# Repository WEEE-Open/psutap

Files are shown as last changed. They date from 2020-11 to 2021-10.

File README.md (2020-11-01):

# PSUtap
The PSUtap is a battery powered device designed to sit between the PSU (power supply unit) and the motherboard of a desktop computer.  
It's purpose is to constantly monitor the power lines (voltage and current) to detect power related issues: short circuits, open circuits, overloads, overvoltages, etc...   
It taps the lines from the main 24 pin ATX connector and the lines from another 4 pin connector to monitor:
* 12V1
* 12V2
* 5V
* 5VSB
* 3V3

## Structure of the device
The device is divided into three different boards, which are mounted on top of each other. From the bottom up, they are:
* the analog board
* the digital board
* the screen module  

The three are connected through male/female headers and communicate through an SPI interface.

## Analog board
This board gets its name from the fact that it has current sensing ICs, voltage sensing voltage dividers and an ADC to transmit the data to the digital board.  
For the current sensing, we've used some [LT6105](https://www.analog.com/media/en/technical-documentation/data-sheets/6105fa.pdf) ICs, which are essentially (differential) voltage controlled current sources. The configuration in our board is not much different than the typical application shown in the schematic.  
For the voltage sensing, we've used some regular voltage dividers, with a bit of margin so that we can also detect overvoltages.  
The ADC is an [AD7708](https://www.analog.com/media/en/technical-documentation/data-sheets/AD7708_7718.pdf), which is a delta-sigma, 16 bits, 10 channels ADC with integrated SPI interface, which is why we chose it, so that we could easily connect it to a uC without using too many wires.

## Digital Board
This board contains the uC, the brain of the entire device, a [CH340G](https://cdn.sparkfun.com/datasheets/Dev/Arduino/Other/CH340DS1.PDF) USB to serial converter,  the battery charging and protection circuit, a USB port and some buttons for the user input.  
The used uC is an [ATmega328P](https://ww1.microchip.com/downloads/en/DeviceDoc/Atmel-7810-Automotive-Microcontrollers-ATmega328P_Datasheet.pdf), which will be flashed with the Arduino bootloader so that it can be easily programmed through the Arduino IDE.  
Its main tasks are:
* reading the data coming from the ADC
* displaying on the screen
* handling user inputs
* interact with the computer through the USB port (data logging/remote control)

## Screen module
The screen module is a 240x320 2.8'' LCD, and the serial number is `tjctm24028-spi`.  
It's purpose is to show the user all the measured voltages and currents at once, so that a problem related with the power lines can be located very quickly, and also graph the voltages and currents wrt time.

## Current state
* The schematic for the analog and the digital board have been finished
* The PCB of the first board has to be redesigned completly
* The PCB of the second board has to be designed from scratch
* All the software for the microcontroller has to be written
* Testing (a lot of testing)

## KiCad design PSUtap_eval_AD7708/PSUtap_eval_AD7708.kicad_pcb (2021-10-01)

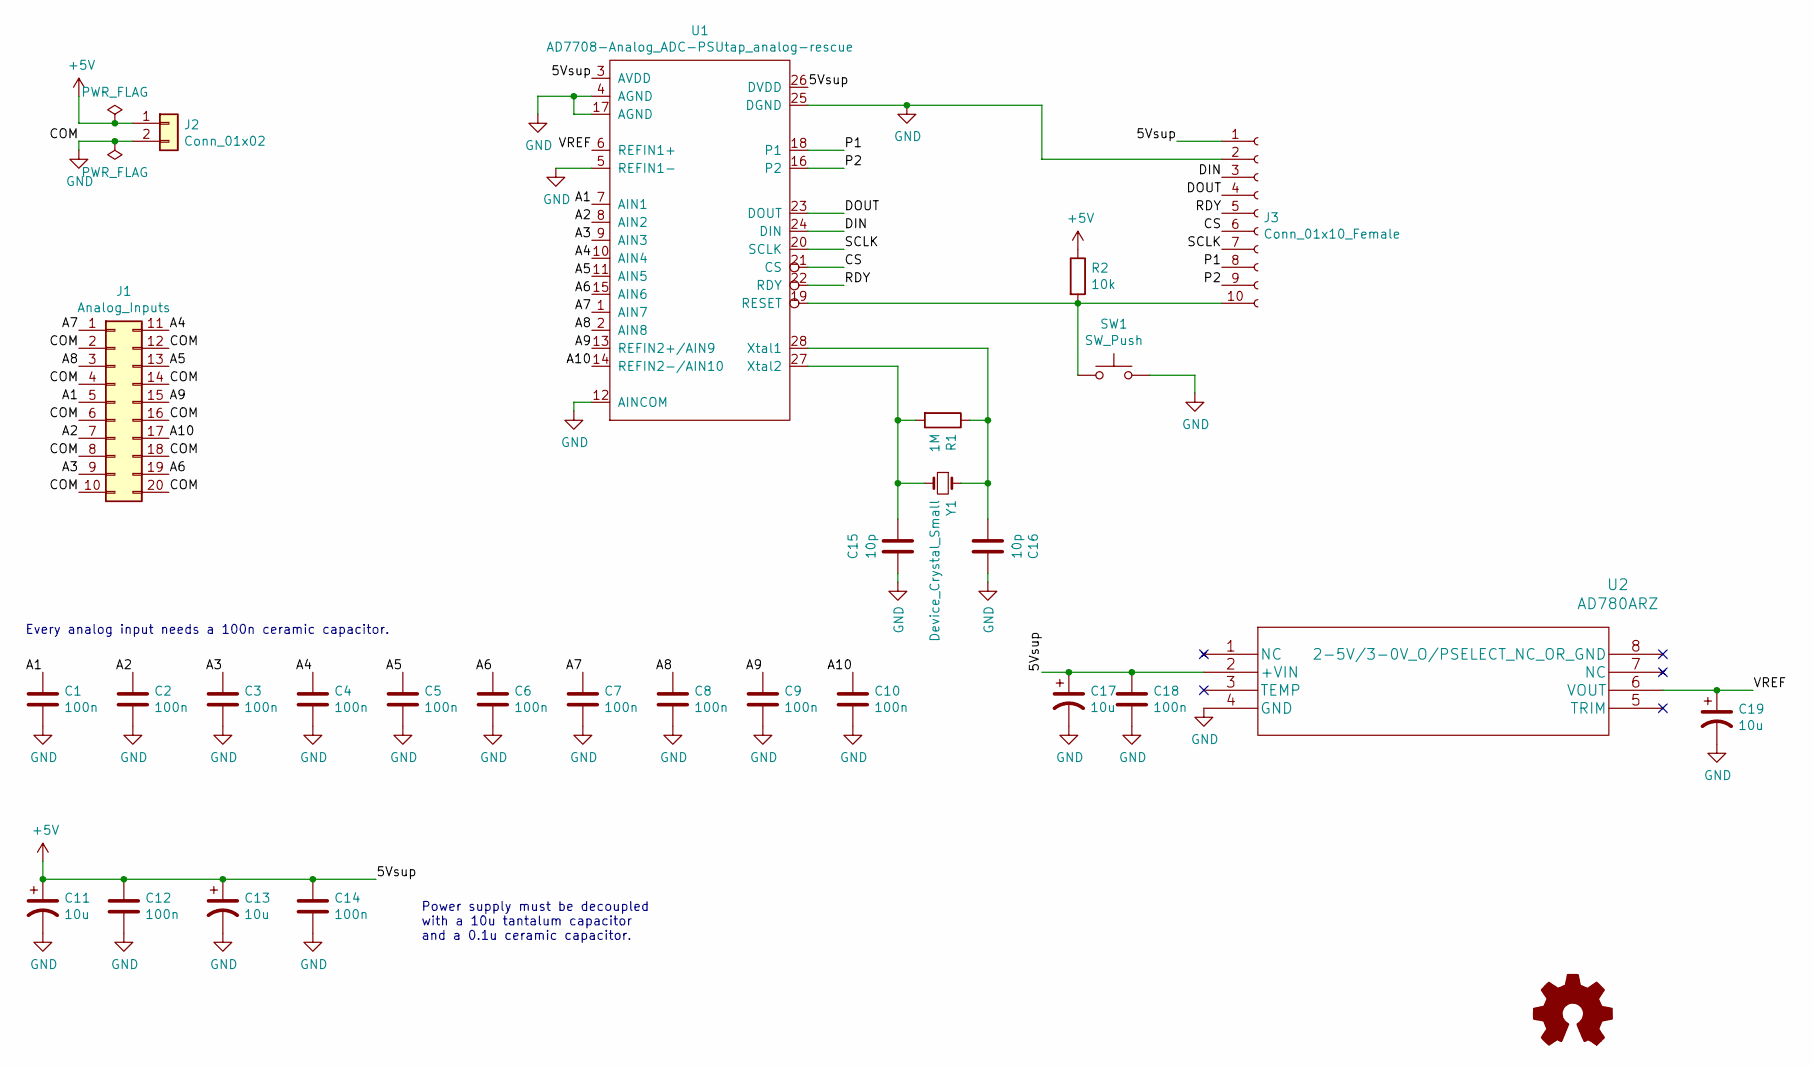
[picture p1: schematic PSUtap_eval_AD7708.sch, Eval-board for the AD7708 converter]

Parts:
C1, C2, C3, C4, C5, C6, C7, C8, C9, C10, C12, C14, C18: 100n; C_0603_1608Metric_Pad1.05x0.95mm_HandSolder
C11, C13, C17, C19: 10u; C_0805_2012Metric
C15, C16: 10p; C_0603_1608Metric_Pad1.05x0.95mm_HandSolder
J1: Analog_Inputs; PinSocket_2x10_P2.54mm_Vertical
J2: Conn_01x02; PinSocket_1x02_P2.54mm_Vertical
J3: Conn_01x10_Female; PinSocket_1x10_P2.54mm_Vertical
R1: 1M; R_0603_1608Metric_Pad1.05x0.95mm_HandSolder
R2: 10k; R_0603_1608Metric_Pad1.05x0.95mm_HandSolder
SW1: SW_Push; SW_SPST_B3U-1000P
U1: AD7708-Analog_ADC-PSUtap_analog-rescue; SOIC-28W_7.5x18.7mm_P1.27mm
U2: AD780ARZ; SSOP-8_3.9x5.05mm_P1.27mm
Y1: Device_Crystal_Small; Crystal_SMD_EuroQuartz_EQ161-2Pin_3.2x1.5mm_HandSoldering

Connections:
+5V: C11.1, C12.1, C13.1, C14.1, C17.1, C18.1, J2.1, J3.1, R2.1, U1.3 (AVDD), U1.26 (DVDD), U2.2 (+VIN)
/A1: C1.1, J1.5, U1.7 (AIN1)
/A2: C2.1, J1.7, U1.8 (AIN2)
/A3: C3.1, J1.9, U1.9 (AIN3)
/A4: C4.1, J1.11, U1.10 (AIN4)
/A5: C5.1, J1.13, U1.11 (AIN5)
/A6: C6.1, J1.19, U1.15 (AIN6)
/A7: C7.1, J1.1, U1.1 (AIN7)
/A8: C8.1, J1.3, U1.2 (AIN8)
/A9: C9.1, J1.15, U1.13 (REFIN2+/AIN9)
/A10: C10.1, J1.17, U1.14 (REFIN2-/AIN10)
/CS: J3.6, U1.21 (CS)
/DIN: J3.3, U1.24 (DIN)
/DOUT: J3.4, U1.23 (DOUT)
/P1: J3.8, U1.18 (P1)
/P2: J3.9, U1.16 (P2)
/RDY: J3.5, U1.22 (RDY)
/SCLK: J3.7, U1.20 (SCLK)
/VREF: C19.1, U1.6 (REFIN1+), U2.6 (VOUT); also elsewhere on the board
GND: C1.2, C2.2, C3.2, C4.2, C5.2, C6.2, C7.2, C8.2, C9.2, C10.2, C11.2, C12.2, C13.2, C14.2, C15.1, C16.1, C17.2, C18.2, C19.2, J1.2, J1.4, J1.6, J1.8, J1.10, J1.12, J1.14, J1.16, J1.18, J1.20, J2.2, J3.2, SW1.2, U1.4 (AGND), U1.5 (REFIN1-), U1.12 (AINCOM), U1.17 (AGND), U1.25 (DGND), U2.4 (GND)
unnamed: C15.2, R1.2, U1.27 (Xtal2), Y1.2
unnamed: C16.2, R1.1, U1.28 (Xtal1), Y1.1
unnamed: J3.10, R2.2, SW1.1, U1.19 (RESET)

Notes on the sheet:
Power supply must be decoupled with a 10u tantalum capacitor and a 0.1u ceramic capacitor.
Every analog input needs a 100n ceramic capacitor.

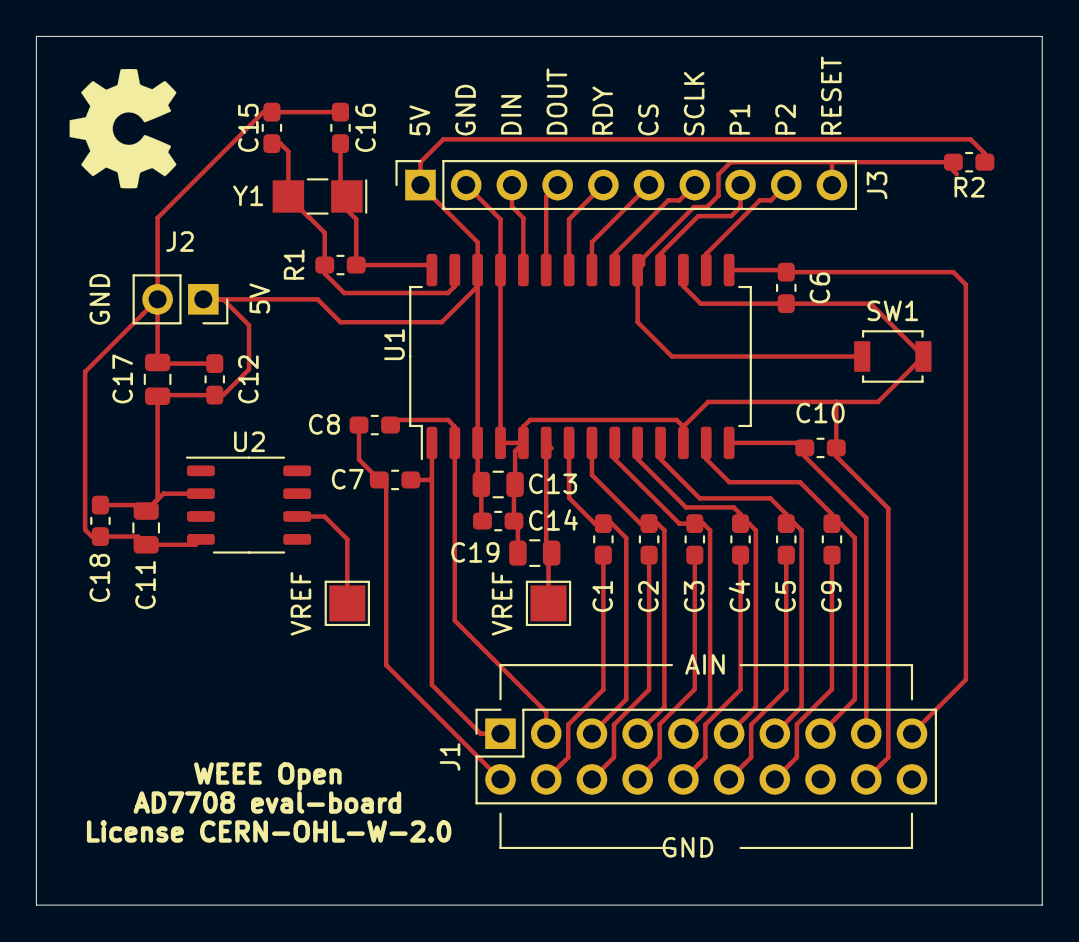
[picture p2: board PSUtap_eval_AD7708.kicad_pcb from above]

Board: 2 copper layers, 55.9 x 48.3 mm, 30 parts (0 on the bottom side), 23 nets.

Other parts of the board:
VREF: TestPoint_Pad_2.0x2.0mm
VREF#2: TestPoint_Pad_2.0x2.0mm

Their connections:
/VREF: VREF.1, VREF#2.1; also elsewhere on the board

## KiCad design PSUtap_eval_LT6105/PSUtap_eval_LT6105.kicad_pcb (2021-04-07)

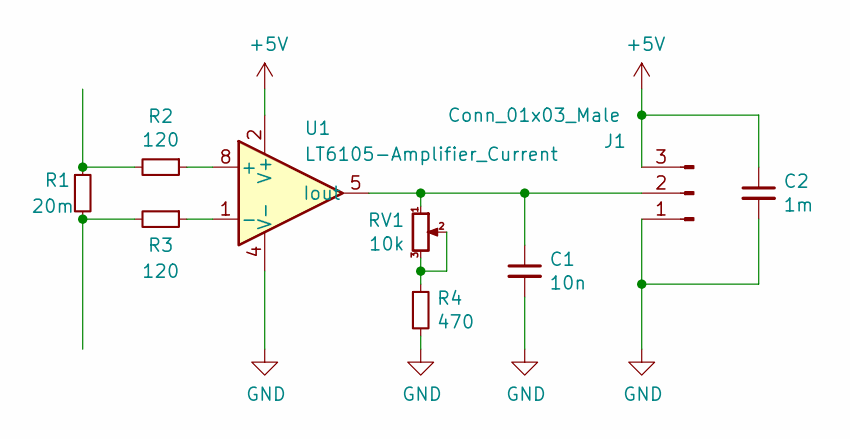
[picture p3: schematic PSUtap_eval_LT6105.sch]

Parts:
C1: 10n; C_0805_2012Metric_Pad1.18x1.45mm_HandSolder
C2: 1m; C_0805_2012Metric_Pad1.18x1.45mm_HandSolder
J1: Conn_01x03_Male; PinHeader_1x03_P2.54mm_Vertical
R1: 20m; R_2512_6332Metric_Pad1.40x3.35mm_HandSolder
R2, R3: 120; R_0805_2012Metric_Pad1.20x1.40mm_HandSolder
R4: 470; R_0805_2012Metric_Pad1.20x1.40mm_HandSolder
RV1: 10k; Potentiometer_Bourns_3296W_Vertical
U1: LT6105-Amplifier_Current; MSOP-8_3x3mm_P0.65mm

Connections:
+5V: C2.1, J1.3, U1.2 (V+)
GND: C1.2, C2.2, J1.1, R4.2, U1.4 (V-)
unnamed: C1.1, J1.2, RV1.1, U1.5 (Iout)
unnamed: R1.1, R2.2
unnamed: R1.2, R3.2
unnamed: R2.1, U1.8 (+)
unnamed: R3.1, U1.1 (-)
unnamed: R4.1, RV1.2, RV1.3

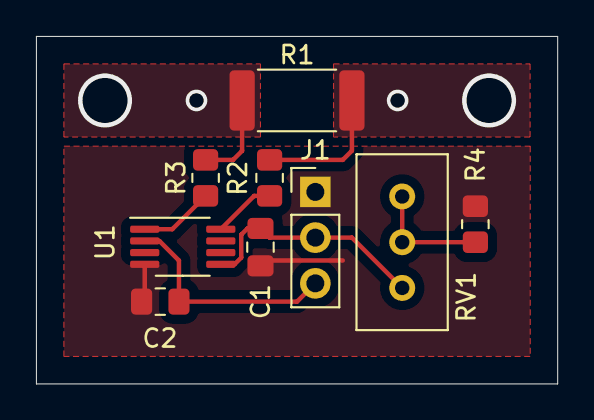
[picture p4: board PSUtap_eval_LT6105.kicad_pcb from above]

Board: 2 copper layers, 29.0 x 19.3 mm, 9 parts (0 on the bottom side), 8 nets.

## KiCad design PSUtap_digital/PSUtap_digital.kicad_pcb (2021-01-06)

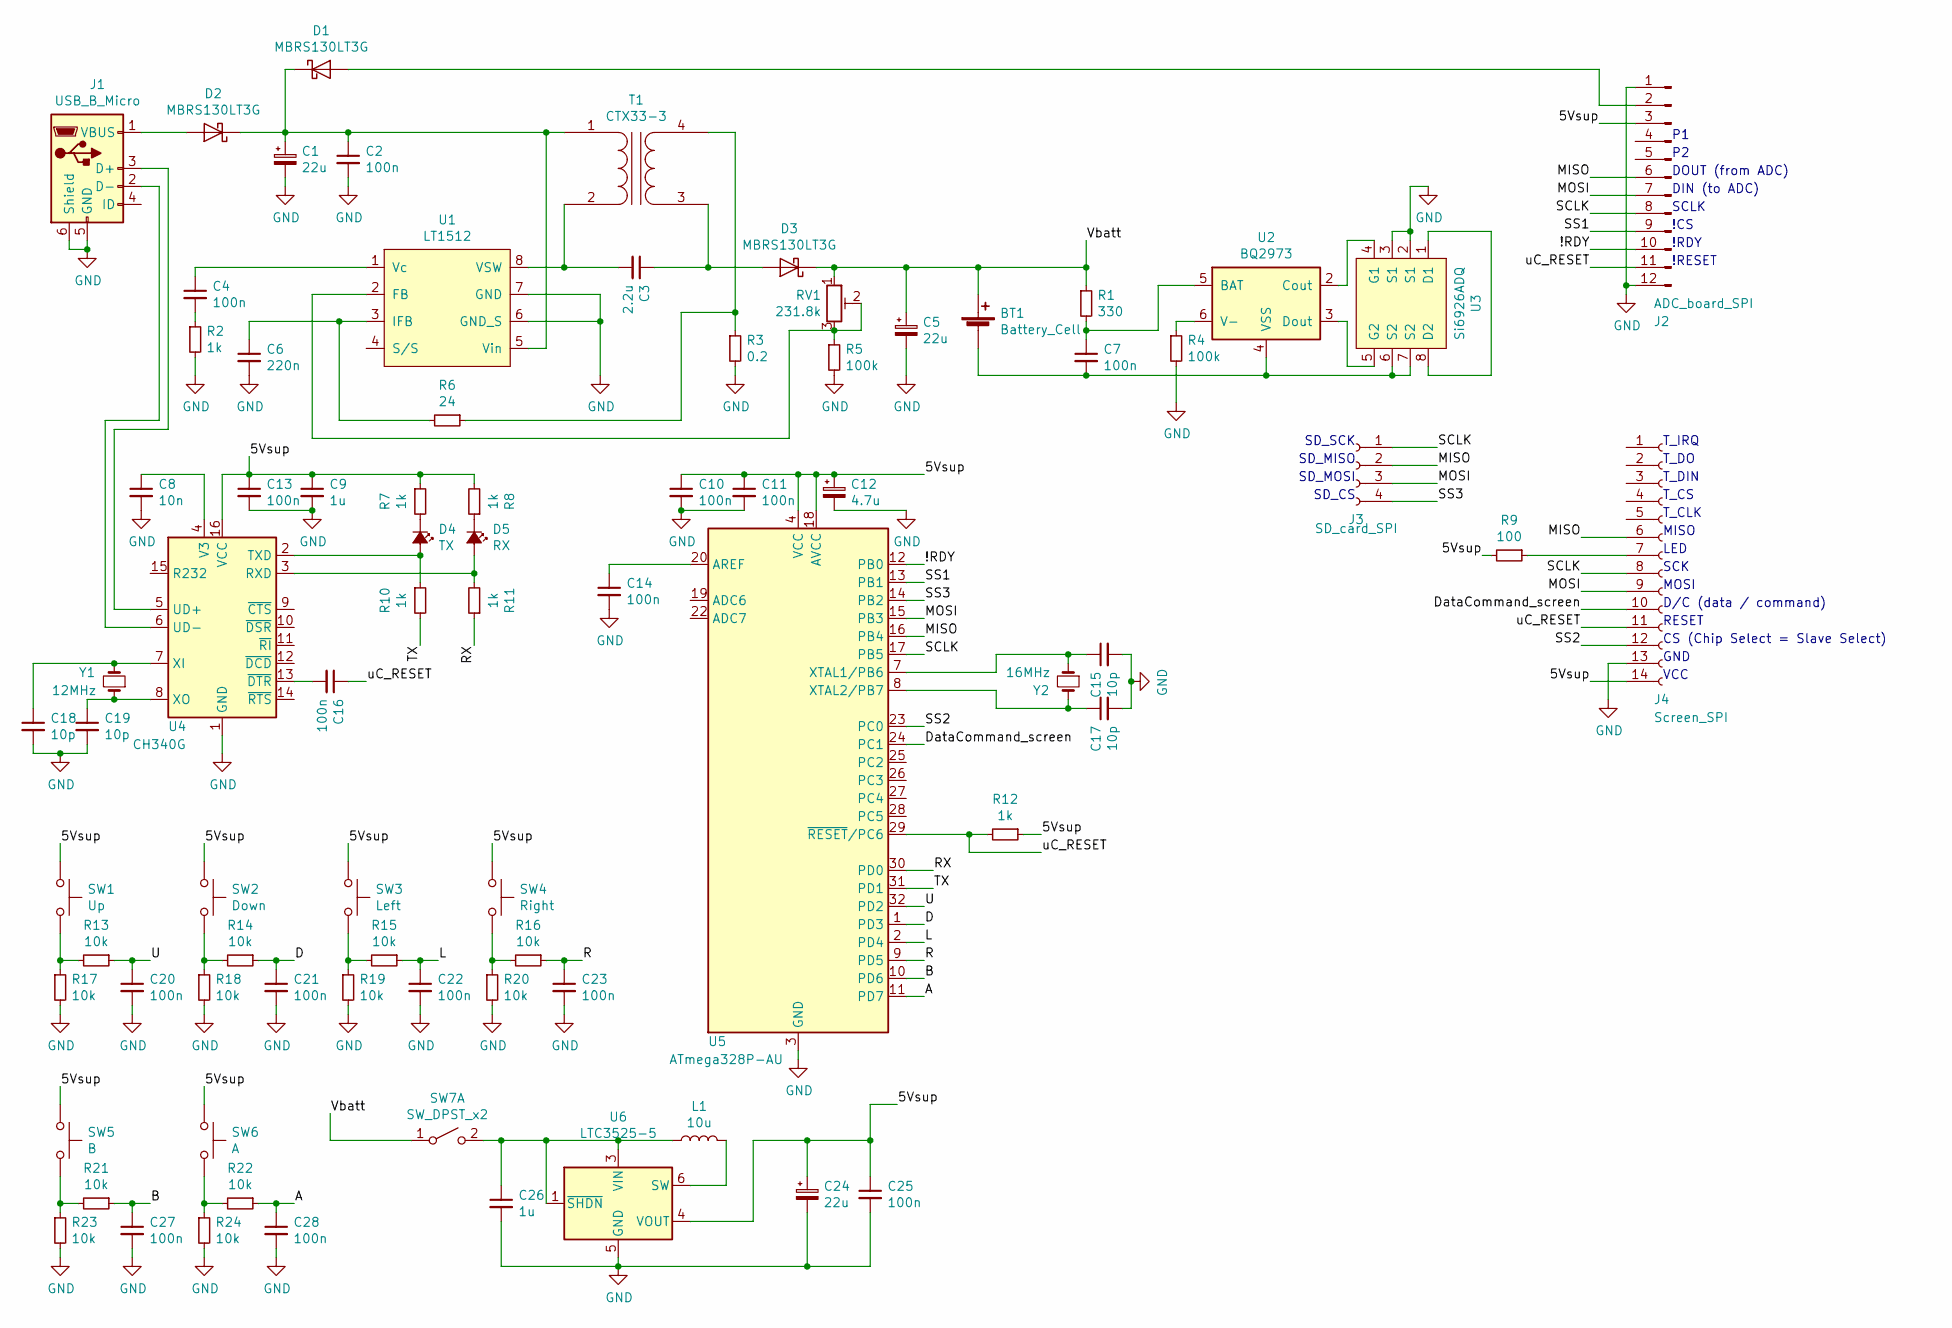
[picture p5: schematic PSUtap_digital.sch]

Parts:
BT1: Battery_Cell; PinHeader_1x02_P2.54mm_Vertical
C1, C5: 22u; C_0805_2012Metric_Pad1.15x1.40mm_HandSolder
C2, C4, C7, C10, C11, C13, C14, C16, C20, C21, C22, C23, C25, C27, C28: 100n; C_0603_1608Metric_Pad1.05x0.95mm_HandSolder
C3: 2.2u; C_0603_1608Metric_Pad1.05x0.95mm_HandSolder
C6: 220n; C_0603_1608Metric_Pad1.05x0.95mm_HandSolder
C8: 10n; C_0603_1608Metric_Pad1.05x0.95mm_HandSolder
C9, C26: 1u; C_0603_1608Metric_Pad1.05x0.95mm_HandSolder
C12: 4.7u; C_0603_1608Metric_Pad1.05x0.95mm_HandSolder
C15, C17, C18, C19: 10p; C_0603_1608Metric_Pad1.05x0.95mm_HandSolder
C24: 22u; C_0603_1608Metric_Pad1.05x0.95mm_HandSolder
D1, D2, D3: MBRS130LT3G; D_SMB_Handsoldering
D4: TX; D_0603_1608Metric_Pad1.05x0.95mm_HandSolder
D5: RX; D_0603_1608Metric_Pad1.05x0.95mm_HandSolder
J1: USB_B_Micro; USB_Micro-B_Molex-105017-0001
J2: ADC_board_SPI; PinHeader_1x12_P2.54mm_Vertical
J3: SD_card_SPI; PinHeader_1x04_P2.54mm_Vertical
J4: Screen_SPI; PinHeader_1x14_P2.54mm_Vertical
L1: 10u; L_Wuerth_MAPI-3012
R1: 330; R_0603_1608Metric_Pad1.05x0.95mm_HandSolder
R2, R7, R8, R10, R11, R12: 1k; R_0603_1608Metric_Pad1.05x0.95mm_HandSolder
R3: 0.2; R_0603_1608Metric_Pad1.05x0.95mm_HandSolder
R4, R5: 100k; R_0603_1608Metric_Pad1.05x0.95mm_HandSolder
R6: 24; R_0603_1608Metric_Pad1.05x0.95mm_HandSolder
R9: 100; R_0603_1608Metric_Pad1.05x0.95mm_HandSolder
R13, R14, R15, R16, R17, R18, R19, R20, R21, R22, R23, R24: 10k; R_0603_1608Metric_Pad1.05x0.95mm_HandSolder
RV1: 231.8k; TRIM_3362P-1-304
SW1: Up; SW_PUSH_6mm
SW2: Down; SW_PUSH_6mm
SW3: Left; SW_PUSH_6mm
SW4: Right; SW_PUSH_6mm
SW5: B; SW_PUSH_6mm
SW6: A; SW_PUSH_6mm
SW7: SW_DPST_x2; PinHeader_1x05_P2.00mm_Vertical
T1: CTX33-3; IND_CTX33-3-R
U1: LT1512; SO-8_3.9x4.9mm_P1.27mm
U2: BQ2973; WSON-6_1.5x1.5mm_P0.5mm
U3: Si6926ADQ; TSSOP-8_4.4x3mm_P0.65mm
U4: CH340G; SOIC-16_3.9x9.9mm_P1.27mm
U5: ATmega328P-AU; TQFP-32_7x7mm_P0.8mm
U6: LTC3525-5; SOT-363_SC-70-6
Y1: 12MHz; Crystal_SMD_5032-2Pin_5.0x3.2mm
Y2: 16MHz; Crystal_SMD_5032-2Pin_5.0x3.2mm

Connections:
/5Vsup: C9.1, C10.1, C11.1, C12.1, C13.1, C24.1, C25.1, J2.3, J4.14, R7.1, R8.2, R9.2, R12.1, SW1.1, SW2.1, SW3.1, SW4.1, SW5.1, SW6.1, U4.16 (VCC), U5.4 (VCC), U5.6 (VCC), U5.18 (AVCC), U6.4 (VOUT)
/!RDY: J2.10, U5.12 (PB0)
/A: C28.1, R22.1, U5.11 (PD7)
/B: C27.1, R21.1, U5.10 (PD6)
/D: C21.1, R14.1, U5.1 (PD3)
/DataCommand_screen: J4.10, U5.24 (PC1)
/L: C22.1, R15.1, U5.2 (PD4)
/MISO: J2.6, J3.2, J4.6, U5.16 (PB4)
/MOSI: J2.7, J3.3, J4.9, U5.15 (PB3)
/R: C23.1, R16.1, U5.9 (PD5)
/RX: R11.1, U5.30 (PD0)
/SCLK: J2.8, J3.1, J4.8, U5.17 (PB5)
/SS1: J2.9, U5.13 (PB1)
/SS2: J4.12, U5.23 (PC0)
/SS3: J3.4, U5.14 (PB2)
/TX: R10.2, U5.31 (PD1)
/U: C20.1, R13.1, U5.32 (PD2)
/uC_RESET: C16.1, J2.11, J4.11, R12.2, U5.29 (~RESET~/PC6)
GND: C1.2, C2.2, C5.2, C6.2, C8.2, C9.2, C10.2, C11.2, C12.2, C13.2, C14.2, C15.2, C17.2, C18.2, C19.2, C20.2, C21.2, C22.2, C23.2, C24.2, C25.2, C26.2, C27.2, C28.2, J1.5 (GND), J1.6 (Shield), J2.1, J2.12, J4.13, R2.2, R3.2, R4.2, R5.2, R17.2, R18.2, R19.2, R20.2, R23.2, R24.2, U1.6 (GND_S), U1.7 (GND), U3.2 (S1), U3.3 (S1), U4.1 (GND), U5.3 (GND), U5.5 (GND), U5.21 (GND), U6.2 (GND), U6.5 (GND)
unnamed: BT1.2 (-), C7.2, U2.4 (VSS), U3.6 (S2), U3.7 (S2)
unnamed: C1.1, C2.1, D1.1 (K), D2.1 (K), T1.1 (AA), U1.5 (Vin)
unnamed: C3.1, D3.2 (A), T1.3 (SA)
unnamed: C3.2, T1.2 (AB), U1.8 (VSW)
unnamed: C4.1, U1.1 (Vc)
unnamed: C4.2, R2.1
unnamed: C6.1, R6.2, U1.3 (IFB)
unnamed: C7.1, R1.2, U2.5 (BAT)
unnamed: C8.1, U4.4 (V3)
unnamed: C14.1, U5.20 (AREF)
unnamed: C15.1, U5.7 (XTAL1/PB6), Y2.1
unnamed: C16.2, U4.13 (~DTR)
unnamed: C17.1, U5.8 (XTAL2/PB7), Y2.2
unnamed: C18.1, U4.7 (XI), Y1.2
unnamed: C19.1, U4.8 (XO), Y1.1
unnamed: D1.2 (A), J2.2
unnamed: D2.2 (A), J1.1 (VBUS)
unnamed: D4.1 (K), R7.2
unnamed: D4.2 (A), R10.1, U4.2 (TXD)
unnamed: D5.1 (K), R8.1
unnamed: D5.2 (A), R11.2, U4.3 (RXD)
unnamed: J1.2 (D-), U4.6 (UD-)
unnamed: J1.3 (D+), U4.5 (UD+)
unnamed: J4.7, R9.1
unnamed: L1.2, U6.6 (SW)
unnamed: R3.1, R6.1, T1.4 (SB)
unnamed: R4.1, U2.6 (V-)
unnamed: R5.1, RV1.2, RV1.3, U1.2 (FB)
unnamed: R13.2, R17.1, SW1.2
unnamed: R14.2, R18.1, SW2.2
unnamed: R15.2, R19.1, SW3.2
unnamed: R16.2, R20.1, SW4.2
unnamed: R21.2, R23.1, SW5.2
unnamed: R22.2, R24.1, SW6.2
unnamed: U2.2 (Cout), U3.4 (G1)
unnamed: U2.3 (Dout), U3.5 (G2)
unnamed: U3.1 (D1), U3.8 (D2)

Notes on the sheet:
DOUT (from ADC)
DIN (to ADC)
SCLK
!CS
!RDY
!RESET
T_IRQ
T_DO
T_DIN
T_CS
T_CLK
MISO
LED
SCK
MOSI
D/C (data / command)
RESET
CS (Chip Select = Slave Select)
GND
VCC
SD_SCK
SD_MISO
SD_MOSI
SD_CS

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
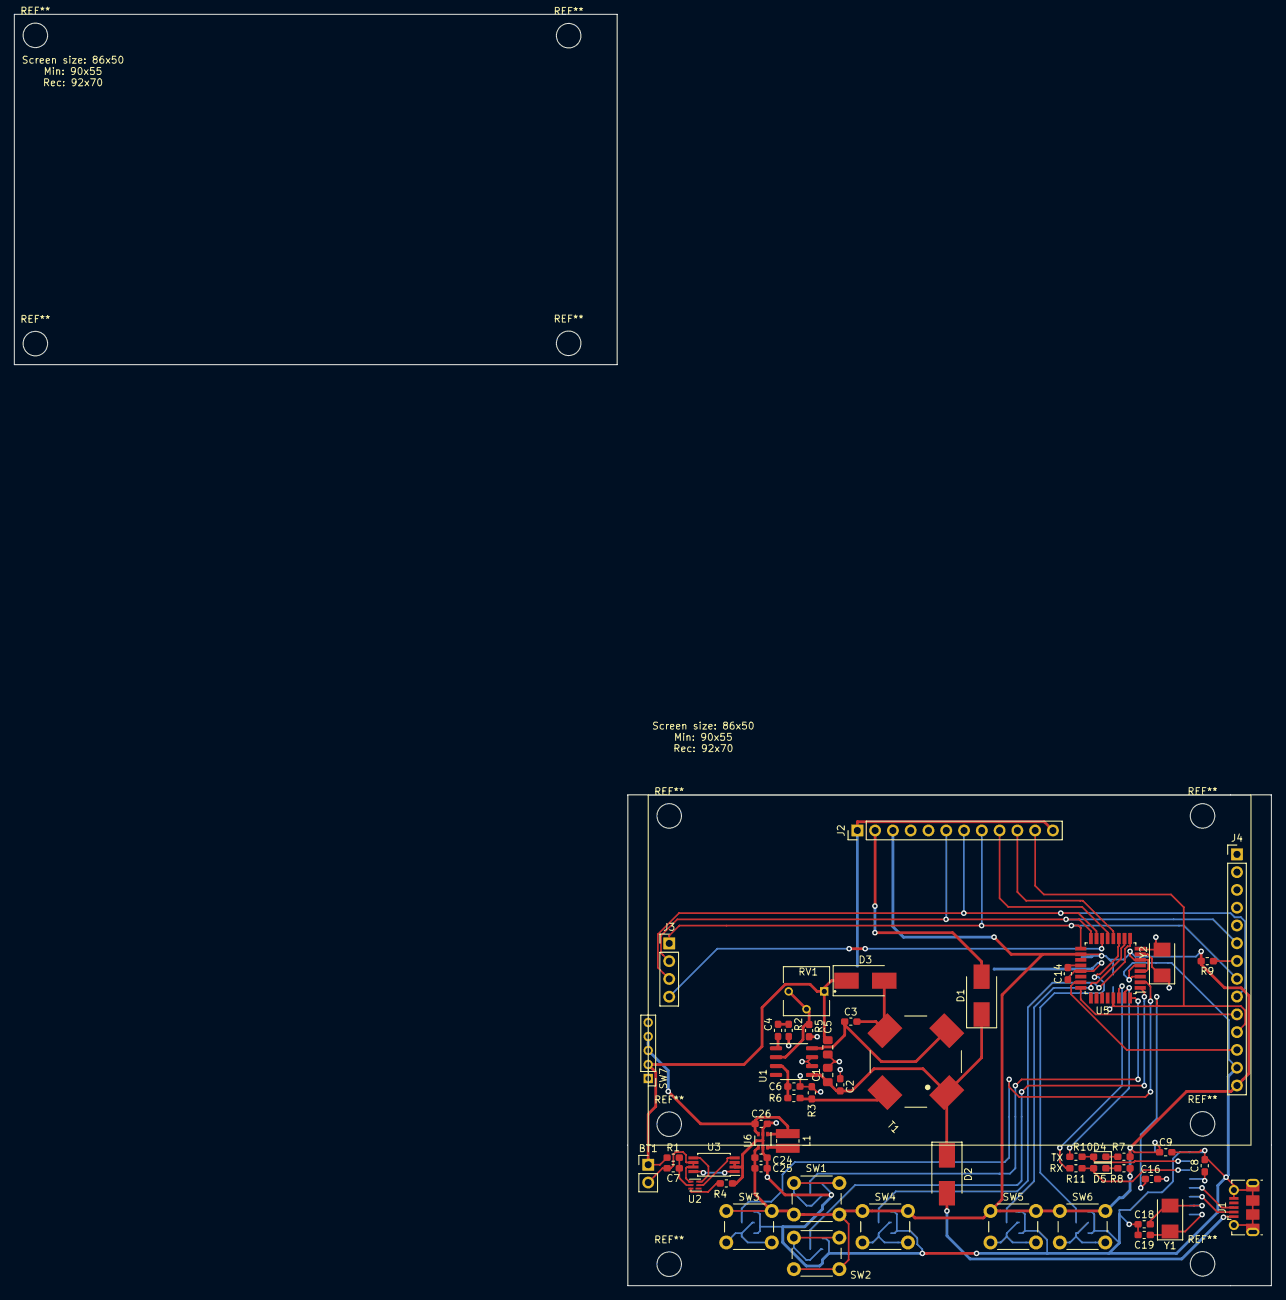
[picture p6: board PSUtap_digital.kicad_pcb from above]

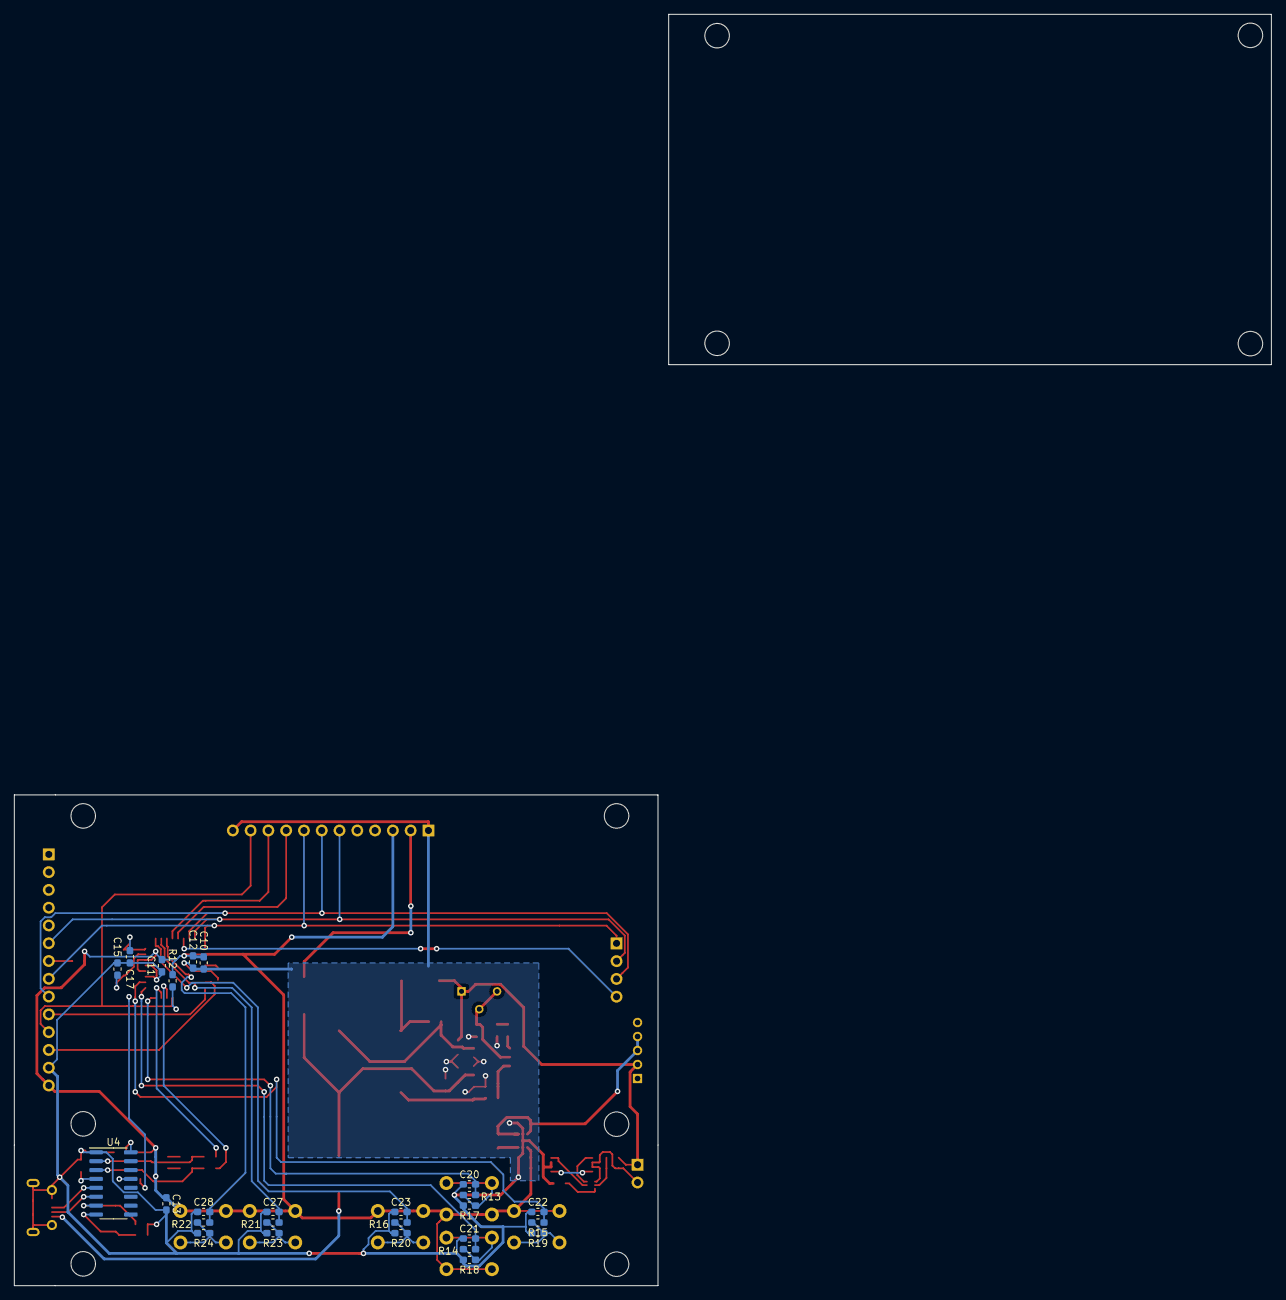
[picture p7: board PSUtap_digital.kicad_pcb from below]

Board: 2 copper layers, 91.9 x 70.1 mm, 80 parts (26 on the bottom side), 58 nets.

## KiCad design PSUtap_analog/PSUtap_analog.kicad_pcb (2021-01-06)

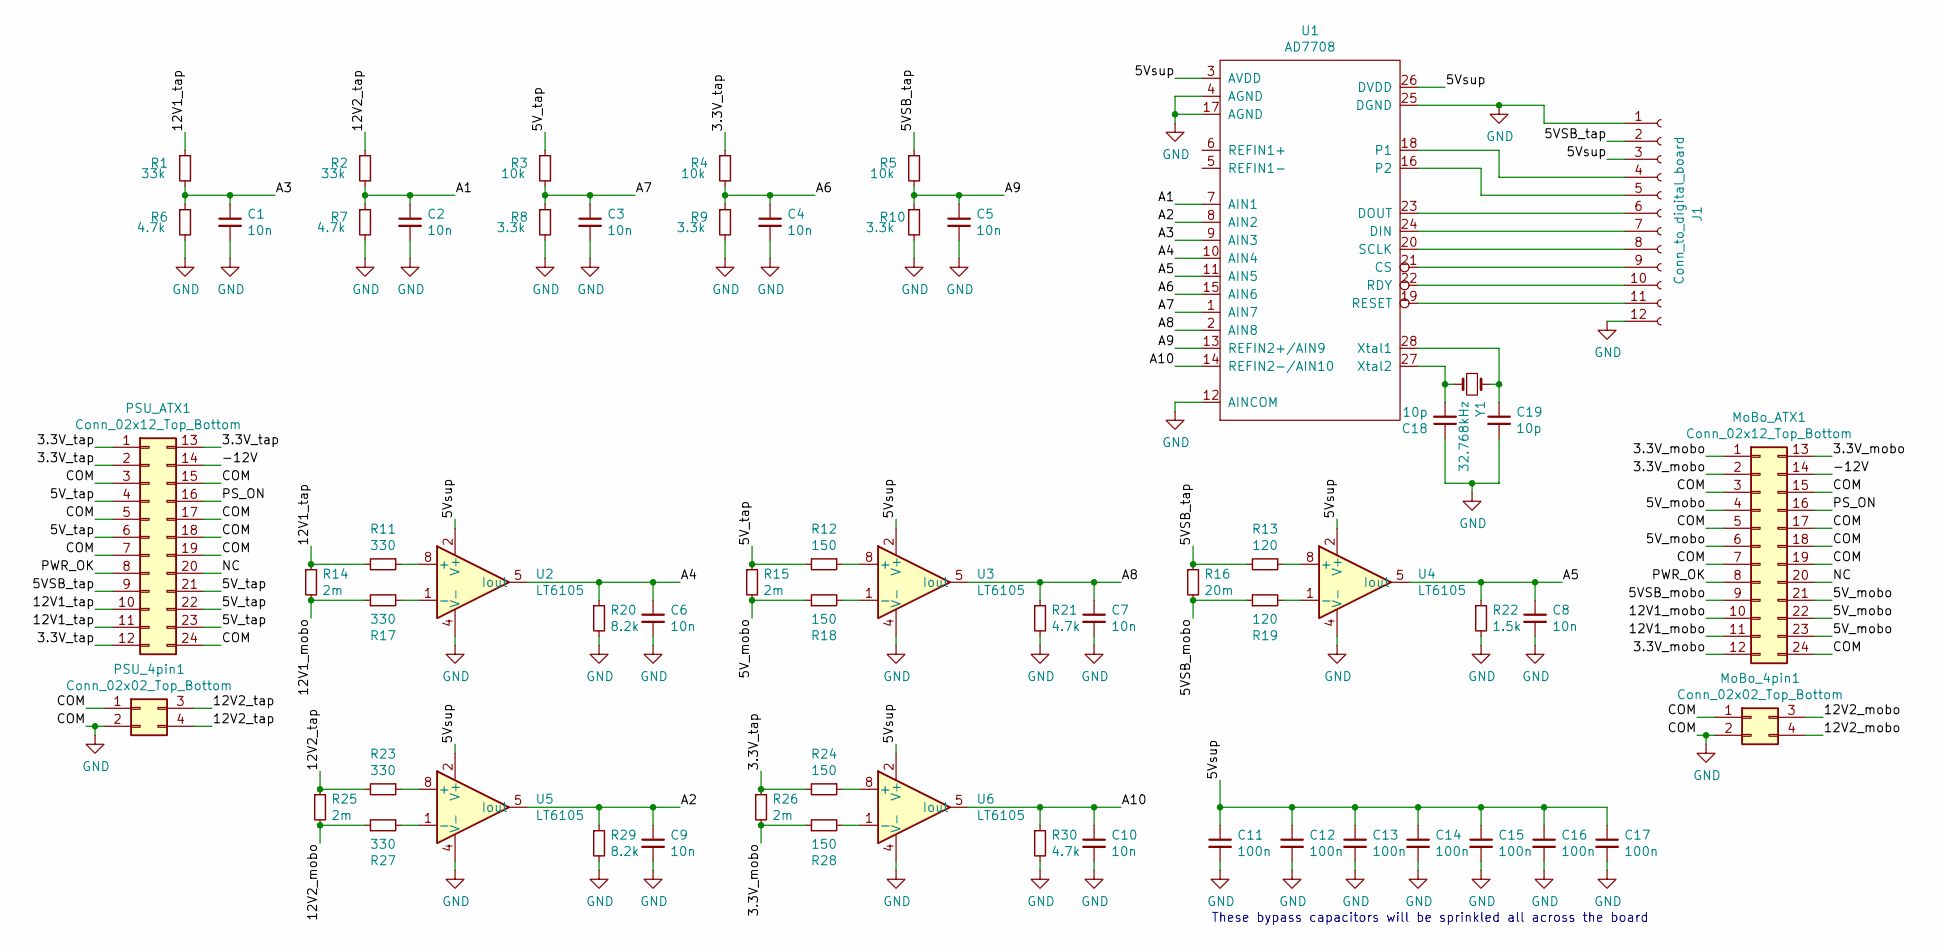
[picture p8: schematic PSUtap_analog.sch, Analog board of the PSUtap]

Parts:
C1, C2, C3, C4, C5, C6, C7, C8, C9, C10: 10n; C_0603_1608Metric_Pad1.05x0.95mm_HandSolder
C11, C12, C13, C14, C15, C16, C17: 100n; C_0603_1608Metric_Pad1.05x0.95mm_HandSolder
C18, C19: 10p; C_0603_1608Metric_Pad1.05x0.95mm_HandSolder
J1: Conn_to_digital_board; PinSocket_1x12_P2.54mm_Vertical
MoBo_4pin1: Conn_02x02_Top_Bottom; Molex_Mini-Fit_Jr_5566-04A_2x02_P4.20mm_Vertical
MoBo_ATX1: Conn_02x12_Top_Bottom; Molex_Mini-Fit_Jr_5566-24A_2x12_P4.20mm_Vertical
PSU_4pin1: Conn_02x02_Top_Bottom; Molex_Mini-Fit_Jr_5566-04A_2x02_P4.20mm_Vertical
PSU_ATX1: Conn_02x12_Top_Bottom; Molex_Mini-Fit_Jr_5566-24A_2x12_P4.20mm_Vertical
R1, R2: 33k; R_0603_1608Metric_Pad1.05x0.95mm_HandSolder
R3, R4, R5: 10k; R_0603_1608Metric_Pad1.05x0.95mm_HandSolder
R6, R7, R21, R30: 4.7k; R_0603_1608Metric_Pad1.05x0.95mm_HandSolder
R8, R9, R10: 3.3k; R_0603_1608Metric_Pad1.05x0.95mm_HandSolder
R11, R17, R23, R27: 330; R_0603_1608Metric_Pad1.05x0.95mm_HandSolder
R12, R18, R24, R28: 150; R_0603_1608Metric_Pad1.05x0.95mm_HandSolder
R13, R19: 120; R_0603_1608Metric_Pad1.05x0.95mm_HandSolder
R14, R15, R25, R26: 2m; R_2512_6332Metric_Pad1.52x3.35mm_HandSolder
R16: 20m; R_0805_2012Metric_Pad1.15x1.40mm_HandSolder
R20, R29: 8.2k; R_0603_1608Metric_Pad1.05x0.95mm_HandSolder
R22: 1.5k; R_0603_1608Metric_Pad1.05x0.95mm_HandSolder
U1: AD7708; SOIC-28W_7.5x18.7mm_P1.27mm
U2, U3, U4, U5, U6: LT6105; MSOP-8_3x3mm_P0.65mm
Y1: 32.768kHz; Crystal_SMD_EuroQuartz_EQ161-2Pin_3.2x1.5mm_HandSoldering

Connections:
/3.3V_mobo: MoBo_ATX1.1, MoBo_ATX1.2, MoBo_ATX1.12, MoBo_ATX1.13, R26.2, R28.1
/3.3V_tap: PSU_ATX1.1, PSU_ATX1.2, PSU_ATX1.12, PSU_ATX1.13, R4.1, R24.2, R26.1
/5VSB_mobo: MoBo_ATX1.9, R16.2, R19.1
/5VSB_tap: J1.2, PSU_ATX1.9, R5.1, R13.2, R16.1
/5V_mobo: MoBo_ATX1.4, MoBo_ATX1.6, MoBo_ATX1.21, MoBo_ATX1.22, MoBo_ATX1.23, R15.2, R18.1
/5V_tap: PSU_ATX1.4, PSU_ATX1.6, PSU_ATX1.21, PSU_ATX1.22, PSU_ATX1.23, R3.1, R12.2, R15.1
/5Vsup: C11.1, C12.1, C13.1, C14.1, C15.1, C16.1, C17.1, J1.3, U1.3 (AVDD), U1.26 (DVDD), U2.2 (V+), U3.2 (V+), U4.2 (V+), U5.2 (V+), U6.2 (V+)
/12V1_mobo: MoBo_ATX1.10, MoBo_ATX1.11, R14.2, R17.1
/12V1_tap: PSU_ATX1.10, PSU_ATX1.11, R1.1, R11.2, R14.1
/12V2_mobo: MoBo_4pin1.3, MoBo_4pin1.4, R25.2, R27.1
/12V2_tap: PSU_4pin1.3, PSU_4pin1.4, R2.1, R23.2, R25.1
/-12V: MoBo_ATX1.14, PSU_ATX1.14
/A1: C2.1, R2.2, R7.1, U1.7 (AIN1)
/A2: C9.1, R29.1, U1.8 (AIN2), U5.5 (Iout)
/A3: C1.1, R1.2, R6.1, U1.9 (AIN3)
/A4: C6.1, R20.1, U1.10 (AIN4), U2.5 (Iout)
/A5: C8.1, R22.1, U1.11 (AIN5), U4.5 (Iout)
/A6: C4.1, R4.2, R9.1, U1.15 (AIN6)
/A7: C3.1, R3.2, R8.1, U1.1 (AIN7)
/A8: C7.1, R21.1, U1.2 (AIN8), U3.5 (Iout)
/A9: C5.1, R5.2, R10.1, U1.13 (REFIN2+/AIN9)
/A10: C10.1, R30.1, U1.14 (REFIN2-/AIN10), U6.5 (Iout)
/NC: MoBo_ATX1.20, PSU_ATX1.20
/PS_ON: MoBo_ATX1.16, PSU_ATX1.16
/PWR_OK: MoBo_ATX1.8, PSU_ATX1.8
GND: C1.2, C2.2, C3.2, C4.2, C5.2, C6.2, C7.2, C8.2, C9.2, C10.2, C11.2, C12.2, C13.2, C14.2, C15.2, C16.2, C17.2, C18.1, C19.2, J1.1, J1.12, MoBo_4pin1.1, MoBo_4pin1.2, MoBo_ATX1.3, MoBo_ATX1.5, MoBo_ATX1.7, MoBo_ATX1.15, MoBo_ATX1.17, MoBo_ATX1.18, MoBo_ATX1.19, MoBo_ATX1.24, PSU_4pin1.1, PSU_4pin1.2, PSU_ATX1.3, PSU_ATX1.5, PSU_ATX1.7, PSU_ATX1.15, PSU_ATX1.17, PSU_ATX1.18, PSU_ATX1.19, PSU_ATX1.24, R6.2, R7.2, R8.2, R9.2, R10.2, R20.2, R21.2, R22.2, R29.2, R30.2, U1.4 (AGND), U1.12 (AINCOM), U1.17 (AGND), U1.25 (DGND), U2.4 (V-), U3.4 (V-), U4.4 (V-), U5.4 (V-), U6.4 (V-)
unnamed: C18.2, U1.27 (Xtal2), Y1.2
unnamed: C19.1, U1.28 (Xtal1), Y1.1
unnamed: J1.4, U1.18 (P1)
unnamed: J1.5, U1.16 (P2)
unnamed: J1.6, U1.23 (DOUT)
unnamed: J1.7, U1.24 (DIN)
unnamed: J1.8, U1.20 (SCLK)
unnamed: J1.9, U1.21 (CS)
unnamed: J1.10, U1.22 (RDY)
unnamed: J1.11, U1.19 (RESET)
unnamed: R11.1, U2.8 (+)
unnamed: R12.1, U3.8 (+)
unnamed: R13.1, U4.8 (+)
unnamed: R17.2, U2.1 (-)
unnamed: R18.2, U3.1 (-)
unnamed: R19.2, U4.1 (-)
unnamed: R23.1, U5.8 (+)
unnamed: R24.1, U6.8 (+)
unnamed: R27.2, U5.1 (-)
unnamed: R28.2, U6.1 (-)

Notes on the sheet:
These bypass capacitors will be sprinkled all across the board

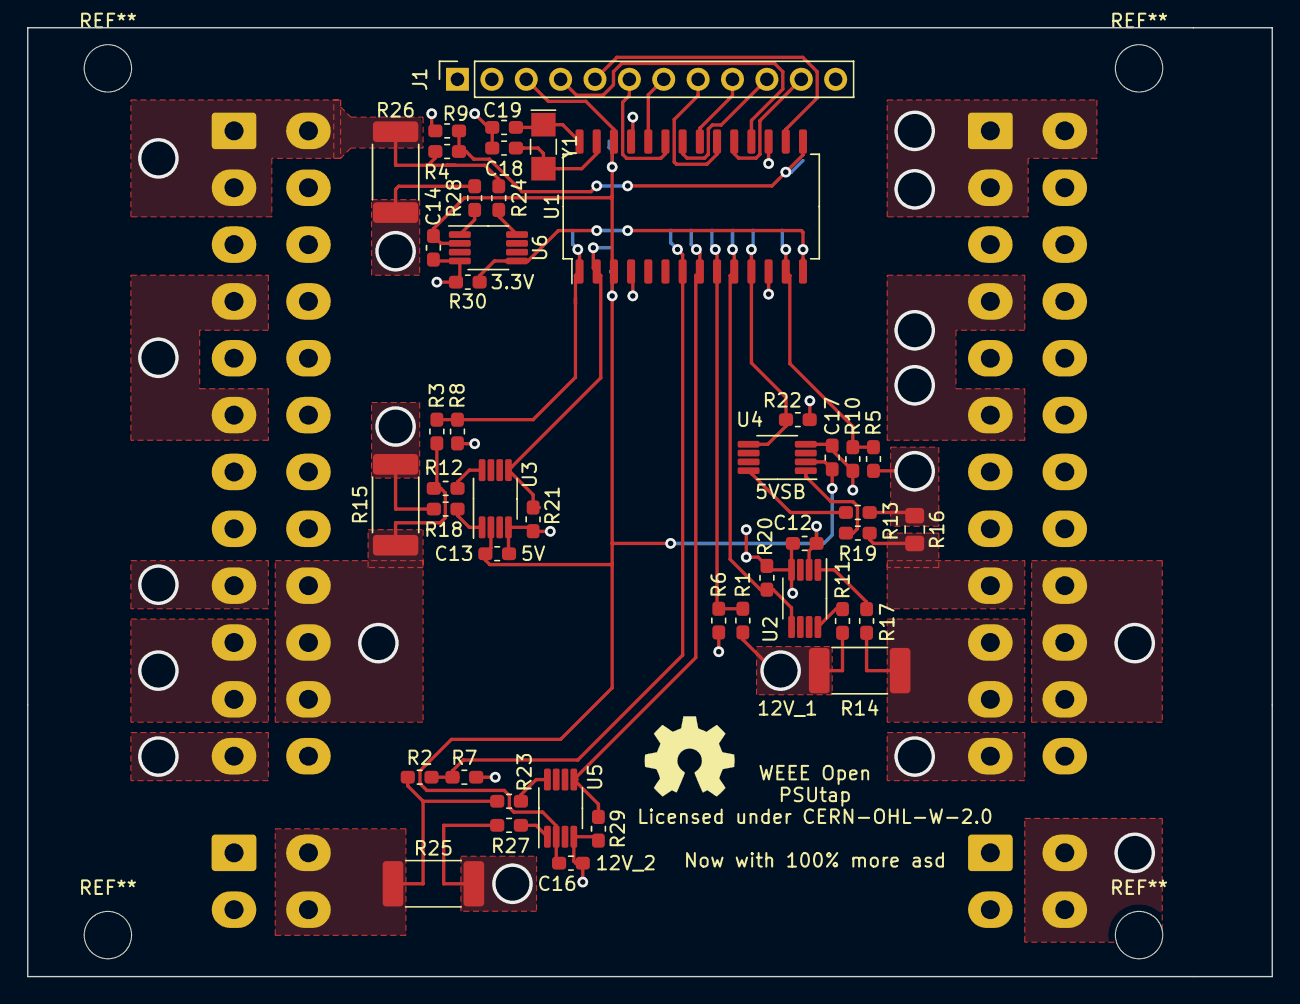
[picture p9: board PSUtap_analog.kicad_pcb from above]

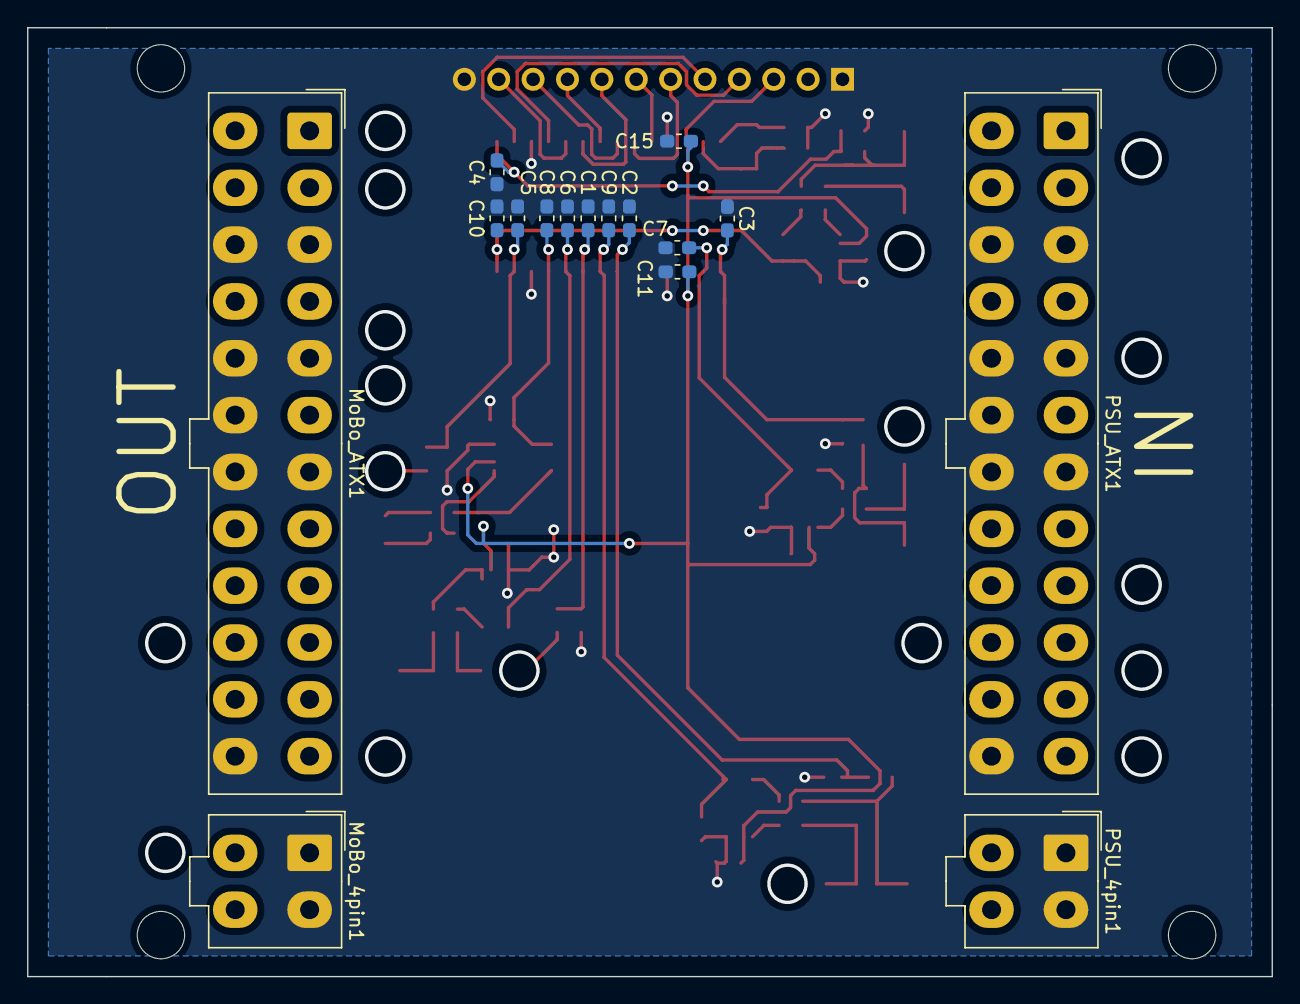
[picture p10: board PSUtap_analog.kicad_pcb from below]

Board: 2 copper layers, 91.9 x 70.1 mm, 61 parts (16 on the bottom side), 46 nets.

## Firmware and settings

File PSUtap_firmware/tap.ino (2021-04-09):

#include <SPI.h>
#include <Adafruit_GFX.h>
#include <Adafruit_ILI9341.h>
#include <SD.h>

//* buttons
#define PIN_U 2 // PD2 = D2
#define PIN_D 3 // PD3 = D3
#define PIN_L 4 // PD4 = D4
#define PIN_R 5 // PD5 = D5
#define PIN_A 7 // PD7 = D7
#define PIN_B 6 // PD6 = D6

enum button { U, D, L, R, A, B };
bool button_state[6];

//* SPI
#define PIN_MOSI 11 // PB3 = D11
#define PIN_MISO 12 // PB4 = D12
#define PIN_SCLK 13 // PB5 = D13
#define PIN_SS_ADC 9 // PB1 = D9
#define PIN_SS_DISP A0 // PC0 = A0
#define PIN_SS_USD 10 // PB2 = D10
#define PIN_DISP_DC A1 // PC1 = A1
//#define PIN_DISP_RST 0 // no display reset pin assigned
//* SPI slave select states
bool state_SS_ADC = 1;
bool state_SS_disp = 1;
bool state_SS_uSD = 1;

//* display declaration
Adafruit_ILI9341 disp = Adafruit_ILI9341(PIN_SS_DISP, PIN_DISP_DC, PIN_MOSI, PIN_SCLK); //_RST and _MISO pins not specified (fallback = -1)

//* uSD card declaration
Sd2Card card;
SdVolume volume;
SdFile root;
uint32_t volume_size;
bool uSD_present = 1;

//* display diagnostics
//* see https://www.newhavendisplay.com/app_notes/ILI9341.pdf
#define DISP_PWR_MODE disp.readcommand8(ILI9341_RDMODE) //idle, sleep, normal, on/off
#define DISP_MADCTL_MODE disp.readcommand8(ILI9341_RDMADCTL) //display print direction, refresh direction
#define DISP_PXL_FORMAT disp.readcommand8(ILI9341_RDPIXFMT) //bpp
#define DISP_IMG_FORMAT disp.readcommand8(ILI9341_RDIMGFMT) //gamma
#define DISP_SELF_DIAG disp.readcommand8(ILI9341_RDSELFDIAG)

unsigned long dispDiag() {
    Serial.print("Display Power Mode: 0x"); Serial.println(DISP_PWR_MODE, HEX);
    Serial.print("MADCTL Mode: 0x"); Serial.println(DISP_MADCTL_MODE, HEX);
    Serial.print("Pixel Format: 0x"); Serial.println(DISP_PXL_FORMAT, HEX);
    Serial.print("Image Format: 0x"); Serial.println(DISP_IMG_FORMAT, HEX);
    Serial.print("Self Diagnostic: 0x"); Serial.println(DISP_SELF_DIAG, HEX);
}

//* display test text
unsigned long dispTestText() {
    disp.fillScreen(ILI9341_BLACK);
    unsigned long start = micros();
    disp.setCursor(0, 0);
    disp.setTextColor(ILI9341_WHITE);  disp.setTextSize(1);
    disp.println("Hello World!");
    disp.setTextColor(ILI9341_YELLOW); disp.setTextSize(2);
    disp.println(1234.56);
    disp.setTextColor(ILI9341_RED);    disp.setTextSize(3);
    disp.println(0xDEADBEEF, HEX);
    disp.println();
    disp.setTextColor(ILI9341_GREEN);
    disp.setTextSize(5);
    disp.println("Groop");
    disp.setTextSize(2);
    disp.println("I implore thee,");
    disp.setTextSize(1);
    disp.println("my foonting turlingdromes.");
    return micros() - start;
}

void setup() {
    //* buttons
    pinMode(PIN_U, INPUT);
    pinMode(PIN_D, INPUT);
    pinMode(PIN_L, INPUT);
    pinMode(PIN_R, INPUT);
    pinMode(PIN_A, INPUT);
    pinMode(PIN_B, INPUT);

    //* SPI
    Serial.begin(9600);
    Serial.println("Hi PC, this is ATMega :)");
    disp.begin();

    //* display initial conditions
    disp.fillScreen(ILI9341_BLACK);
    disp.setCursor(0, 0);
    disp.setTextColor(ILI9341_WHITE);  disp.setTextSize(1);
    disp.println("Hi, this is PSUtap\n");

    //* uSD card
    disp.print("\nInitializing uSD card...");
    if(!SD.begin(PIN_SS_USD)) {
        Serial.println("\nCard initialization failed, or card not present");
        uSD_present = 0;
    } else {
        Serial.println("\nCard initialized");

        //* type
        disp.print("\nCard type:    ");
        switch (card.type()) {
        case SD_CARD_TYPE_SD1: disp.print("SD1"); break;
        case SD_CARD_TYPE_SD2: disp.print("SD2"); break;
        case SD_CARD_TYPE_SDHC: disp.print("SDHC"); break;
        default: disp.print("Unknown"); break;
        }
        //* find FAT volume
        if(!volume.init(card)) {
            disp.println("\nCould not find FAT16/FAT32 volume.\nMake sure you've formatted the card");
        } else {
            //* first FAT volume info
            volume_size = volume.blocksPerCluster(); // collection of blocks
            volume_size *= volume.clusterCount();
            volume_size /= 2; // block = 512B <==> 2 blocks = 1KB
            disp.print("\nVolume size:    ");
            disp.print(volume_size);
            disp.print("KB    (");
            disp.print((float)volume_size/1024.0);
            disp.print("GB)");
            disp.print("\nFiles found on the card (name, date and size in bytes):");
            root.openRoot(volume);
            root.ls(LS_R | LS_DATE | LS_SIZE);
            root.close();
        }
    }

    disp.print("\n");

}

void loop() {
    //* read buttons
    button_state[U] = digitalRead(PIN_U);
    button_state[D] = digitalRead(PIN_D);
    button_state[L] = digitalRead(PIN_L);
    button_state[R] = digitalRead(PIN_R);
    button_state[A] = digitalRead(PIN_A);
    button_state[B] = digitalRead(PIN_B);



    //* buttons press check
    if(button_state[U] == 1) { disp.println("U"); delay(100); };
    if(button_state[D] == 1) { disp.println("D"); delay(100); };
    if(button_state[L] == 1) { disp.println("L"); delay(100); };
    if(button_state[R] == 1) { disp.println("R"); delay(100); };
    if(button_state[A] == 1) { dispTestText(); delay(100); };
    if(button_state[B] == 1) { dispDiag(); delay(100); };

}

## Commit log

2020-11-01 Added all the project files
    [PSUtap_analog.kicad_pcb, PSUtap_analog.sch, PSUtap_digital.kicad_pcb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]
2020-11-12 Updated analog board PCB and started digital board PSB
    [PSUtap_analog.kicad_pcb, PSUtap_analog.sch, PSUtap_digital.kicad_pcb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]
2020-11-19 Added ATMega firmware 1.0-alpha
    + pin assignments
    + display SPI connection
    + mSD SPI connection
    + display basic info & print tests
    + mSD basic info
    + buttons press check
2020-11-19 Caching of project footprints
    KiCad "digital rescue" of externally sourced footprints into cache
    [PSUtap_digital.sch]
2020-11-23 Fixed uSD card SDI init
    [tap.ino]
2020-11-23 Fixed uSD volume info
    Now it only prints uSD volume info if it finds a volume
    [tap.ino]
2020-11-28 Copied the digital PCB for parallel collaboration
    [PSUtap_digital - Copy.kicad_pcb]
2020-12-13 Removed PCB copies, added xtal to ADC in analog board, finished digital board's PCB
    [PSUtap_analog.kicad_pcb, PSUtap_analog.sch, PSUtap_digital - Copy.kicad_pcb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]
2021-01-06 Updated PCBs to not have vias on component pads
    [PSUtap_analog.kicad_pcb, PSUtap_digital.kicad_pcb]
2021-03-06 fixed uSD volume_size declaration
    [tap.ino]
2021-04-07 created evaluation board for LT6105
    [PSUtap_eval_LT6105.kicad_pcb, PSUtap_eval_LT6105.sch]
2021-04-07 updated project with custom library
    [PSUtap_eval_LT6105.kicad_pcb, PSUtap_eval_LT6105.sch]
2021-04-09 updated kicad projects caches
    [PSUtap_analog.sch, PSUtap_digital.sch]
2021-04-09 improved buttons state array
    removed separate bools for each button, added enum for button names, consolidated button_state array throughout the code
    also slightly improved code readability
2021-04-15 created evaluation board for AD7708
    [PSUtap_eval_AD7708.kicad_pcb, PSUtap_eval_AD7708.sch]
2021-05-12 single-sided evaluation board for AD7708
    [PSUtap_eval_AD7708.kicad_pcb, PSUtap_eval_AD7708.sch]
2021-05-13 removed case notes
2021-09-23 Shrink AD7708 PCB
    [PSUtap_eval_AD7708.kicad_pcb]
2021-10-01 Separate WEEE and OPEN with space
    [PSUtap_eval_AD7708.kicad_pcb]

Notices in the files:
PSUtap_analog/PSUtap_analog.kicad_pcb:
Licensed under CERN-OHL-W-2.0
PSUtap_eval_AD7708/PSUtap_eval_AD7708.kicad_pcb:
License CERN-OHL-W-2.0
